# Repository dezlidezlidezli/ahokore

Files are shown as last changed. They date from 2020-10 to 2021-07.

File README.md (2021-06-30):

  # ahokore

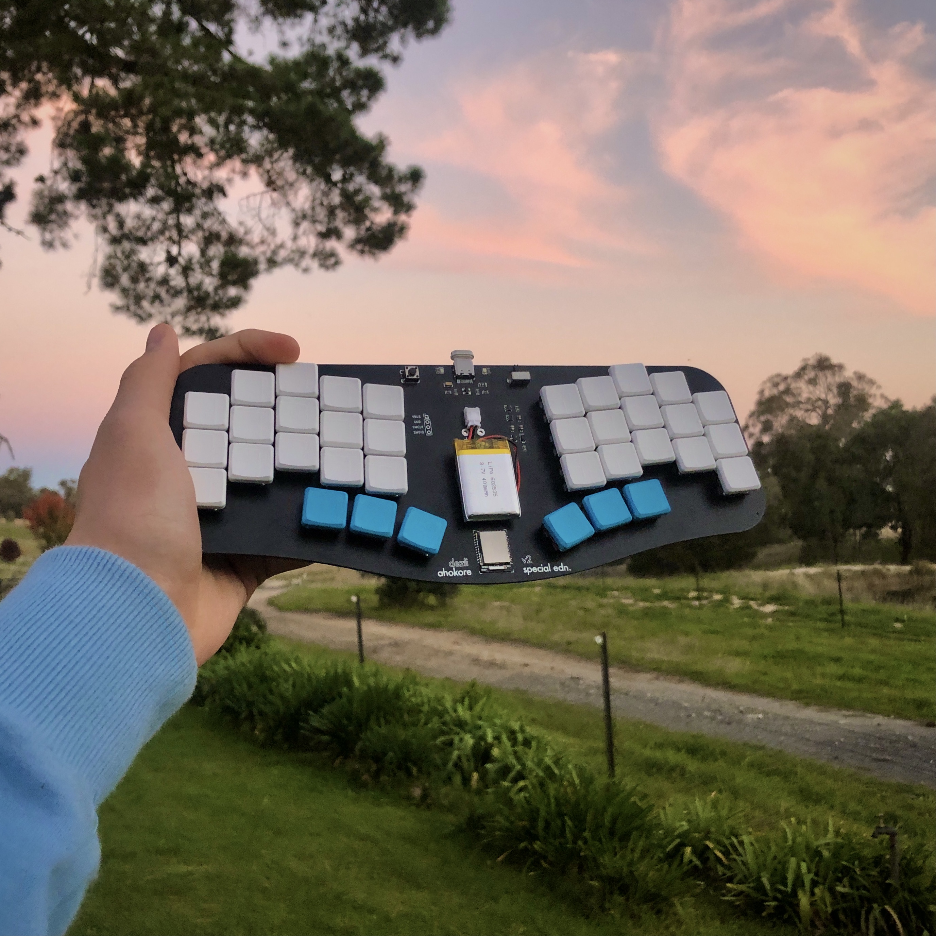
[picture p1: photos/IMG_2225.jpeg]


Ahokore is a 36-key one-piece split keyboard, with full wireless functionality. Stagger is copied from the Ferris, as I found that very comfortable. The name is "wireless" translated into Maori.

V1 is tested to be fully working, and uses a nice!nano.

V2 has been tested and is fully working, and a small group-buy has been run. Extras will be available within a few weeks (written on 30/6/21), on store.dez.li.

If you'd like to produce the board yourself, or modify these files, I reccomend using the v2-fantail

All work in this repository is released into the public domain. See the license file for more details!

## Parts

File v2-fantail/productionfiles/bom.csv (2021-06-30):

Item # | Designator | Quantity | Manufacturer | Mfg Part # | Description/Value | Package/Footprint | Type | Substitute for compatible/comparable alternative?
1 | SW1 | 1 | Schurter Inc. | SWITCH TACTILE SPST-NO 0.05A 12V 6mmx6mm | SW_SPST | 6mmx6mm switch | THT | Yes
2 | BT1 | 1 | JST Sales America Inc. | S2B-PH-K-S(LF)(SN) | Connector Header Through Hole, Right Angle 2 position 0.079" (2.00mm) | JST_PH_S2B-PH-K_1x02_P2.00mm_Horizontal | THT | No
3 | SW38 | 1 | C&K | OS102011MA1QN1 | SWITCH SLIDE SPDT 100MA 12V | OS102011MA1QN1 | THT | No
4 | USB1 | 1 | Korean Hroparts Elec | TYPE-C-31-M-12 | HRO-TYPE-C-31-M-12 | HRO-TYPE-C-31-M-12 | THT + USB (connector) | No
5 | D40 | 1 | Leiditech | SR05 | 5V 6V 23V 3A SOT-143 TVS | SOT-143 | SMD | Yes
6 | C4,C3 | 2 | Samsung Electro-Mechanics | CL21B105KBFNNNE | 1uF ±10% 50V X7R 0805 Capacitors | 0805 | SMD | Yes
7 | C2 | 1 | FH(Guangdong Fenghua Advanced Tech) | 1206B472K202NT | 4.7nF ±10% 2kV X7R 1206 Capacitor | 1206 | SMD | Yes
8 | R9,R4 | 2 | Uniroyal Elec | 0805W8F1001T5E | 1kΩ ±1% 0.125W ±100ppm/℃ 0805 Chip Resistor | 0805 | SMD | Yes
9 | D39 | 1 | Hubei KENTO Elec | 17-21SUYC/TR8 | Yellow 592~594nm 0805 LED | 0805 | SMD | Yes
10 | U4 | 1 | Holyiot | YJ-18010 | nRF52840_holyiot_18010 | nRF52840_holyiot_18010 | SMD | No
11 | D33,D8,D14,D38,D37,D36,D35,D34,D32,D31,D30,D29,D28,D27,D26,D25,D24,D23,D22,D21,D20,D19,D18,D17,D16,D15,D13,D12,D11,D10,D9,D7,D6,D5,D4,D3 | 36 | Diotec | 1N4148W | Diode Standard 75V 150mA Surface Mount SOD-123F | SOD-123 | SMD | Yes
12 | U3 | 1 | Youtai Semiconductor Co., Ltd. | TP4054 | SOT-23-5L PMIC - Battery Management | SOT-23-5 | SMD | Yes
13 | U2 | 1 | Diodes Incorporated | AP2112K-3.3TRG1 | Fixed 6V 3.3V 400mV @ 600mA SOT-25 Dropout Regulators(LDO) | SOT-23-5 | SMD | Yes
14 | R8 | 1 | Uniroyal Elec | 0805W8F2004T5E | 2MΩ ±1% 0.125W ±100ppm/℃ 0805 Chip Resistor | 0805 | SMD | Yes
15 | R7 | 1 | Uniroyal Elec | 0805W8F8063T5E | 806kΩ ±1% 0.125W ±100ppm/℃ 0805 Chip Resistor | 0805 | SMD | Yes
16 | R6 | 1 | Uniroyal Elec | 0805W8F1004T5E | 1MΩ ±1% 0.125W ±100ppm/℃ 0805 Chip Resistor | 0805 | SMD | Yes
17 | R5,R1 | 2 | Uniroyal Elec | 0805W8F5101T5E | 5.1kΩ ±1% 0.125W ±100ppm/℃ 0805 Chip Resisto | 0805 | SMD | Yes
18 | R3,R2 | 2 | Uniroyal Elec | 0805W8F1002T5E | 10kΩ ±1% 0.125W ±100ppm/℃ 0805 Chip Resistor | 0805 | SMD | Yes
19 | Q1 | 1 | BORN | AO3401A | P-Channel -30V 4.2A 2V @ 250uA 50mΩ @ 4.1A,10V 1.4W SOT-23 MOSFET | SOT-23 | SMD | Yes
20 | F1 | 1 | Littelfuse | 1206L050/15YR | Polymeric 15V 1A 100ms 750mΩ 1206 PTC Resettable Fuses | 1206 | SMD | Yes
21 | D2 | 1 | Foshan NationStar Optoelectronics | NCD0805R1 | Red 615~630nm 0805 Light Emitting Diodes (LED) | 0805 | SMD | Yes
22 | D1 | 1 | LGE | 1N5819W | 40V 1A 900mV @ 3A SOD-123 Schottky Barrier Diodes (SBD) | SOD-123 | SMD | Yes
23 | C1 | 1 | Samsung Electro-Mechanics | CL21A475KAQNNNE | 4.7uF ±10% 25V X5R 0805 Capacitors MLCC | 805 | SMD | Yes

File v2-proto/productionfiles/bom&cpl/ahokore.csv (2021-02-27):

Comment | Designator | Footprint | LCSC Part #（optional）
Battery_Cell | BT1 | CONN-TH_A2001WR-2P | C225207
1uF | C4,C3 | 0805 | C28323
SR05 | D40 | SOT-143 | C384891
4.7n | C2 | 1206 | C41017
1k | R9,R4 | 0805 | C17513
LED_Small | D39 | 0805 | C2296
D_Small | D33,D8,D14,D38,D37,D36,D35,D34,D32,D31,D30,D29,D28,D27,D26,D25,D24,D23,D22,D21,D20,D19,D18,D17,D16,D15,D13,D12,D11,D10,D9,D7,D6,D5,D4,D3 | SOD-123 | C81598
HRO-TYPE-C-31-M-12 | USB1 | TYPE-C-31_L8.94_W7.3 | C165948
TP4054 | U3 | SOT-23-5 | C32574
AP2112K-3.3 | U2 | SOT-23-5 | C51118
2M | R8 | 0805 | C26112
806k | R7 | 0805 | C63494
1M | R6 | 0805 | C17514
5.1k | R5,R1 | 0805 | C27834
10k | R3,R2 | 0805 | C17414
AO3401A | Q1 | SOT-23-3 | C306862
500ma | F1 | 1206 | C151162
POWERLED | D2 | 0805 | C84256
1N5819 | D1 | SOD-123 | C402219
4.7uF | C1 | 0805 | C1779

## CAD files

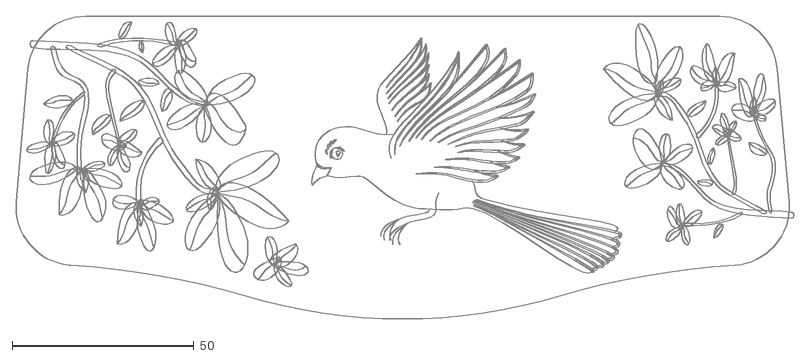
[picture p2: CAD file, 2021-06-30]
Ahokore.dxf
213.8 x 83.3

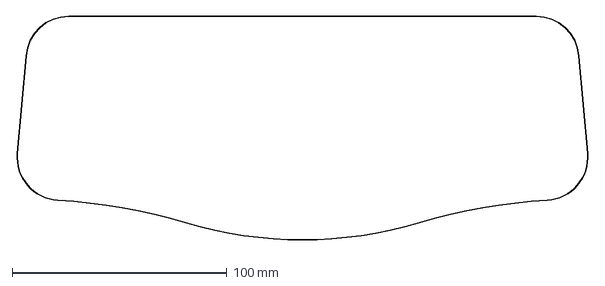
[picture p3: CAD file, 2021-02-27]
v2-fantail/v2edgecuts.dxf
266.5 x 106.7 mm

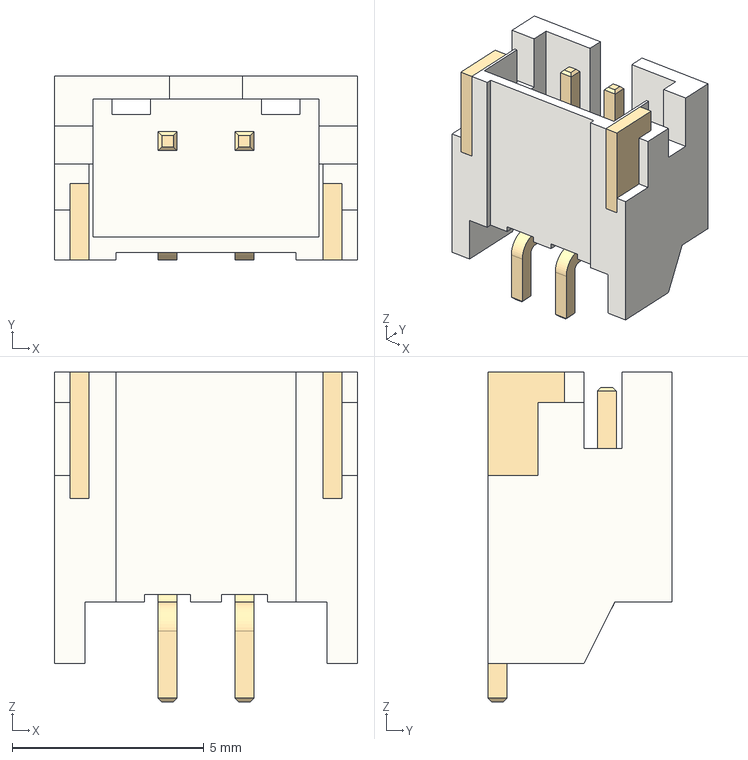
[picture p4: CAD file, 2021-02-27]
v2-proto/S2B-PH-SM4-TB.stp
7.90 x 4.80 x 8.60 mm

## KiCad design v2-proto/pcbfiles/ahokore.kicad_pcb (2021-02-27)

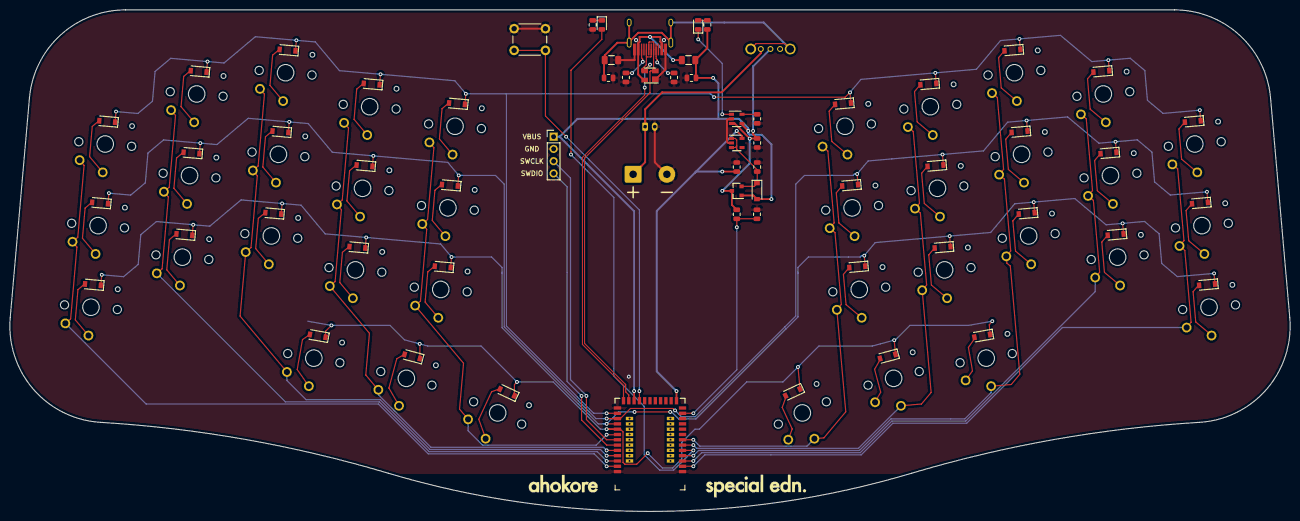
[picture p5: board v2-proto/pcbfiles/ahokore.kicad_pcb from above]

Board: 2 copper layers, 265.7 x 104.1 mm, 100 parts (0 on the bottom side), 71 nets.

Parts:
BT1: Battery_Cell; JST_PH_S2B-PH-K_1x02_P2.00mm_Horizontal
BT2: Battery_Cell; custombatteryconnector
C1: 4.7uF; C_0805_2012Metric
C2: 4.7n; C_1206_3216Metric
C3, C4: 1uF; C_0805_2012Metric
D1: 1N5819; D_SOD-123
D2: POWERLED; D_0805_2012Metric
D3, D4, D5, D6, D7, D8, D9, D10, D11, D12, D13, D14, D15, D16, D17, D18, D19, D20, D21, D22, D23, D24, D25, D26, D27, D28, D29, D30, D31, D32, D33, D34, D35, D36, D37, D38: D_Small; D_SOD-123
D39: LED_Small; D_0805_2012Metric
D40: SR05; SOT-143
F1: 500ma; Fuse_1206_3216Metric
J1: Conn_01x04_Female; PinHeader_1x04_P2.54mm_Vertical
Q1: AO3401A; SOT-23
R1, R5: 5.1k; R_0805_2012Metric
R2, R3: 10k; R_0805_2012Metric
R4, R9: 1k; R_0805_2012Metric
R6: 1M; R_0805_2012Metric
R7: 806k; R_0805_2012Metric
R8: 2M; R_0805_2012Metric
SW1: SW_SPST; custom-reset-switch
SW2, SW3, SW4, SW5, SW6, SW7, SW8, SW9, SW10, SW11, SW12, SW13, SW14, SW15, SW16, SW17, SW18, SW19, SW20, SW21, SW22, SW23, SW24, SW25, SW26, SW27, SW28, SW29, SW30, SW31, SW32, SW33, SW34, SW35, SW36, SW37: SW_Push; Choc_PG1350_Choc_Spacing
SW38: SW_SPDT; OS102011MA1QN1
U2: AP2112K-3.3; SOT-23-5
U3: TP4054; SOT-23-5
U4: nRF52840_holyiot_18010
USB1: HRO-TYPE-C-31-M-12; HRO-TYPE-C-31-M-12-HandSoldering

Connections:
BVOLT: R7.1, R8.2, U4.12
COL0: SW2.2, SW12.2, SW22.2, U4.36
COL1: SW3.2, SW13.2, SW23.2, U4.35
COL2: SW4.2, SW14.2, SW24.2, SW32.2, U4.34
COL3: SW5.2, SW15.2, SW25.2, SW33.2, U4.33
COL4: SW6.2, SW16.2, SW26.2, SW34.2, U4.30
COL5: SW7.2, SW17.2, SW27.2, SW35.1, U4.7
COL6: SW8.2, SW18.2, SW28.2, SW36.1, U4.6
COL7: SW9.2, SW19.2, SW29.2, SW37.1, U4.4
COL8: SW10.2, SW20.2, SW30.2, U4.3
COL9: SW11.2, SW21.2, SW31.2, U4.2
D+: D40.3, U4.24, USB1.6, USB1.8
D-: D40.2, U4.23, USB1.5, USB1.7
Earth: C2.2, R6.2, SW38.0, USB1.13
GND: BT1.2, BT2.2, C1.2, C2.1, C3.2, C4.2, D40.1, J1.2, R1.1, R2.2, R3.1, R5.1, R6.1, R8.1, R9.2, SW1.2, U2.2, U3.2, U4.1, U4.25, U4.37, USB1.1, USB1.12
LED_1: D39.2, U4.5
unnamed: BT1.1, BT2.1, SW38.1
unnamed: C4.1, D1.1, Q1.2, U2.1, U2.3
unnamed: D2.1, U3.1
unnamed: D2.2, R4.2
unnamed: D3.2, SW2.1
unnamed: D4.2, SW3.1
unnamed: D5.2, SW4.1
unnamed: D6.2, SW5.1
unnamed: D7.2, SW6.1
unnamed: D8.2, SW7.1
unnamed: D9.2, SW8.1
unnamed: D10.2, SW9.1
unnamed: D11.2, SW10.1
unnamed: D12.2, SW11.1
unnamed: D13.2, SW12.1
unnamed: D14.2, SW13.1
unnamed: D15.2, SW14.1
unnamed: D16.2, SW15.1
unnamed: D17.2, SW16.1
unnamed: D18.2, SW17.1
unnamed: D19.2, SW18.1
unnamed: D20.2, SW19.1
unnamed: D21.2, SW20.1
unnamed: D22.2, SW21.1
unnamed: D23.2, SW22.1
unnamed: D24.2, SW23.1
unnamed: D25.2, SW24.1
unnamed: D26.2, SW25.1
unnamed: D27.2, SW26.1
unnamed: D28.2, SW27.1
unnamed: D29.2, SW28.1
unnamed: D30.2, SW29.1
unnamed: D31.2, SW30.1
unnamed: D32.2, SW31.1
unnamed: D33.2, SW32.1
unnamed: D34.2, SW33.1
unnamed: D35.2, SW34.1
unnamed: D36.2, SW35.2
unnamed: D37.2, SW36.2
unnamed: D38.2, SW37.2
unnamed: D39.1, R9.1
unnamed: R1.2, USB1.4
unnamed: R3.2, U3.5
unnamed: R5.2, USB1.10
RAW: D40.4, F1.2, USB1.2, USB1.11
RESET: SW1.1, U4.21
ROW0: D3.1, D4.1, D5.1, D6.1, D7.1, D8.1, D9.1, D10.1, D11.1, D12.1, U4.26
ROW1: D13.1, D14.1, D15.1, D16.1, D17.1, D18.1, D19.1, D20.1, D21.1, D22.1, U4.27
ROW2: D23.1, D24.1, D25.1, D26.1, D27.1, D28.1, D29.1, D30.1, D31.1, D32.1, U4.28
ROW3: D33.1, D34.1, D35.1, D36.1, D37.1, D38.1, U4.29
SWC: J1.3, U4.31
SWD: J1.4, U4.32
VBAT: C1.1, Q1.3, R7.2, SW38.2, U3.3
VBUS: D1.2, F1.1, J1.1, Q1.1, R2.1, R4.1, U3.4, U4.22
VDD_NRF: C3.1, U2.5, U4.14

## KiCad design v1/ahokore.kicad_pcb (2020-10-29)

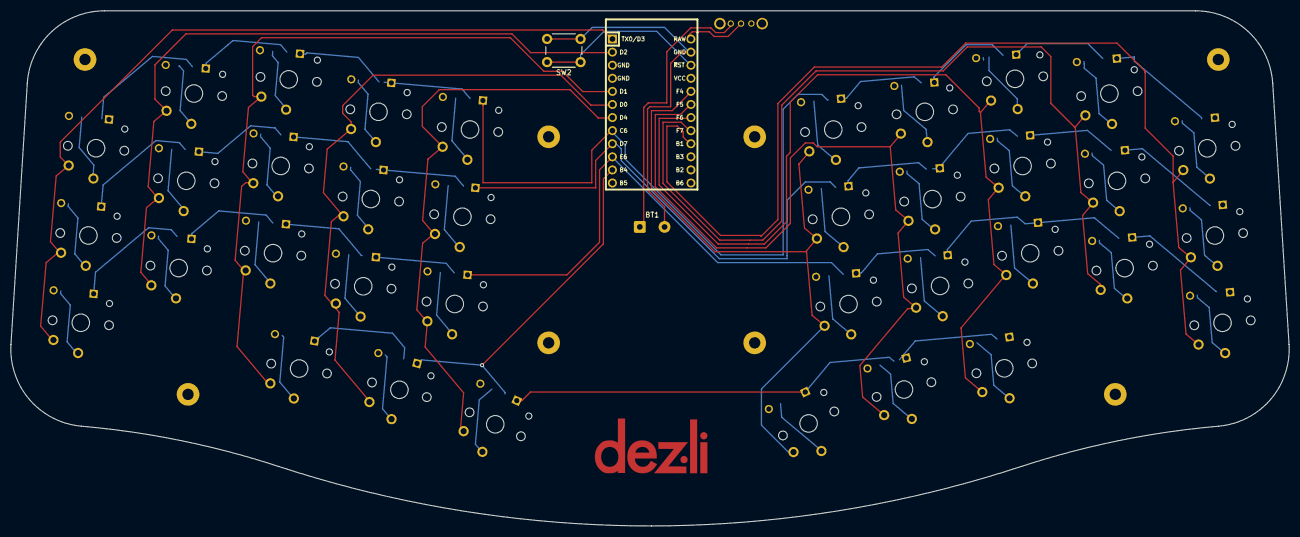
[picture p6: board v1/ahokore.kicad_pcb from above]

Board: 2 copper layers, 248.2 x 100.0 mm, 76 parts (0 on the bottom side), 54 nets.

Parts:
BT1: Battery_Cell; battery
D1, D2, D3, D4, D5, D6, D7, D8, D9, D10, D11, D12, D13, D14, D15, D16, D17, D18, D19, D20, D21, D22, D23, D24, D25, D26, D27, D28, D29, D30, D31, D32, D33, D34, D35, D36: D_Small; Diode-Hybrid-Back
SW1: SW_SPDT; OS102011MA1QN1
SW2: SW_Push; SW_PUSH_6mm
SW3, SW4, SW5, SW6, SW7, SW8, SW9, SW10, SW11, SW12, SW13, SW14, SW15, SW16, SW17, SW18, SW19, SW20, SW21, SW22, SW23, SW24, SW25, SW26, SW27, SW28, SW29, SW30, SW31, SW32, SW33, SW34, SW35, SW36, SW37, SW38: SW_Push; customchocfootprint
U1: ProMicro; ArduinoProMicro

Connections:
+BATT: SW1.2, U1.24
COL0: SW3.2, SW13.2, SW23.2, U1.1
COL1: SW4.2, SW14.2, SW24.2, U1.2
COL2: SW5.2, SW15.2, SW25.2, SW33.2, U1.5
COL3: SW6.2, SW16.2, SW26.2, SW34.2, U1.6
COL4: SW7.2, SW17.2, SW27.2, SW35.2, U1.7
COL5: SW8.2, SW18.2, SW28.2, SW36.2, U1.20
COL6: SW9.2, SW19.2, SW29.2, SW37.2, U1.19
COL7: SW10.2, SW20.2, SW30.2, SW38.2, U1.18
COL8: SW11.2, SW21.2, SW31.2, U1.17
COL9: SW12.2, SW22.2, SW32.2, U1.16
GND: BT1.2, SW2.2, U1.23
unnamed: BT1.1, SW1.1
unnamed: D1.2, SW3.1
unnamed: D2.2, SW4.1
unnamed: D3.2, SW5.1
unnamed: D4.2, SW6.1
unnamed: D5.2, SW7.1
unnamed: D6.2, SW8.1
unnamed: D7.2, SW9.1
unnamed: D8.2, SW10.1
unnamed: D9.2, SW11.1
unnamed: D10.2, SW12.1
unnamed: D11.2, SW13.1
unnamed: D12.2, SW14.1
unnamed: D13.2, SW15.1
unnamed: D14.2, SW16.1
unnamed: D15.2, SW17.1
unnamed: D16.2, SW18.1
unnamed: D17.2, SW19.1
unnamed: D18.2, SW20.1
unnamed: D19.2, SW21.1
unnamed: D20.2, SW22.1
unnamed: D21.2, SW23.1
unnamed: D22.2, SW24.1
unnamed: D23.2, SW25.1
unnamed: D24.2, SW26.1
unnamed: D25.2, SW27.1
unnamed: D26.2, SW28.1
unnamed: D27.2, SW29.1
unnamed: D28.2, SW30.1
unnamed: D29.2, SW31.1
unnamed: D30.2, SW32.1
unnamed: D31.2, SW33.1
unnamed: D32.2, SW34.1
unnamed: D33.2, SW35.1
unnamed: D34.2, SW36.1
unnamed: D35.2, SW37.1
unnamed: D36.2, SW38.1
ROW0: D1.1, D2.1, D3.1, D4.1, D5.1, D6.1, D7.1, D8.1, D9.1, D10.1, U1.8
ROW1: D11.1, D12.1, D13.1, D14.1, D15.1, D16.1, D17.1, D18.1, D19.1, D20.1, U1.9
ROW2: D21.1, D22.1, D23.1, D24.1, D25.1, D26.1, D27.1, D28.1, D29.1, D30.1, U1.10
ROW3: D31.1, D32.1, D33.1, D34.1, D35.1, D36.1, U1.11
RST: SW2.1, U1.22

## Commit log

2020-10-20 add blank kicad files
    [akohore.kicad_pcb, akohore.sch]
2020-10-20 kicad file updates
    [akohore.kicad_pcb]
2020-10-20 layout pcb
    [akohore.kicad_pcb]
2020-10-21 add diodes
    [akohore.kicad_pcb]
2020-10-21 last commit before edgecuts
    [akohore.kicad_pcb]
2020-10-21 nvm, not the last one
    [akohore.kicad_pcb]
2020-10-22 routing half
    [akohore.kicad_pcb, akohore.sch]
2020-10-22 finished, no checks yet
    [akohore.kicad_pcb]
2020-10-22 i'm basically done :)
    [akohore.kicad_pcb]
2020-10-29 production pcb files, silk and mounting holes add
    [akohore.kicad_pcb]
2020-10-29 i forgot to save before updates
    [ahokore.kicad_pcb]
2020-12-09 stuff :)
    [ahokore-B_Cu.gbl, ahokore-B_Mask.gbs, ahokore-B_Paste.gbp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]
2020-12-09 formatting of repo update
    [ahokore.kicad_pcb, ahokore.sch]
2020-12-09 add photos and gerbers
2021-07-03 add bottom plate files
    [ahokore-B_Cu.gbl, ahokore-B_Mask.gbs, ahokore-B_SilkS.gbo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]

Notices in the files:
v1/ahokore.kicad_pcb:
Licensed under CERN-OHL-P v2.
